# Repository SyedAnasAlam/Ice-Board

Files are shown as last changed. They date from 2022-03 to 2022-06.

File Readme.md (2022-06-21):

# Ice Board 
Ice Board is a FPGA development board containing the ICE40HX4k from Lattice.  
## Parts
- Lattice ICE40HX4K FPGA
- W25X20CL 2Mbit SPI Flash for storing configuration bitstream (104MHz)
- USB-C for configuring the FPGA using [IceBoard Programmer](https://github.com/SyedAnasAlam/IceBoard-Programmer) 
    - Also has option for programming the flash with a external device though breakout headers
- Requires 5V supply which can be supplied from either USB port or barrel jack (selectable with a header)
- FTDI4222 for USB to SPI conversion
- 64 x IO pins  
  
3D Rendering of the PCB

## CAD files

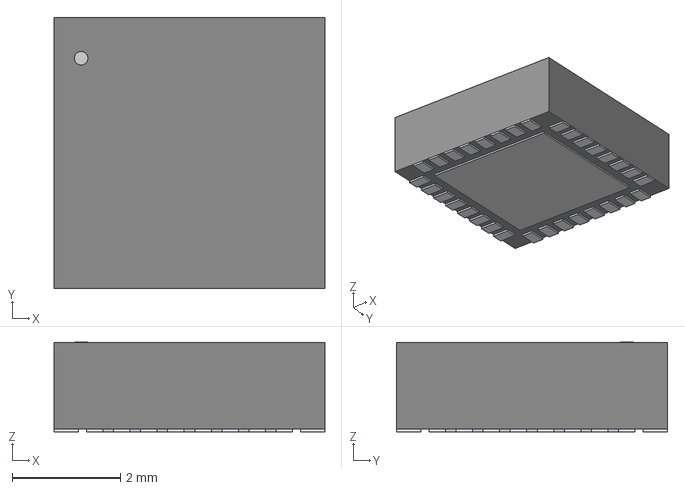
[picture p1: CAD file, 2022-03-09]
components/3D.models/FT4222HQ.step
5.00 x 5.00 x 1.65 mm

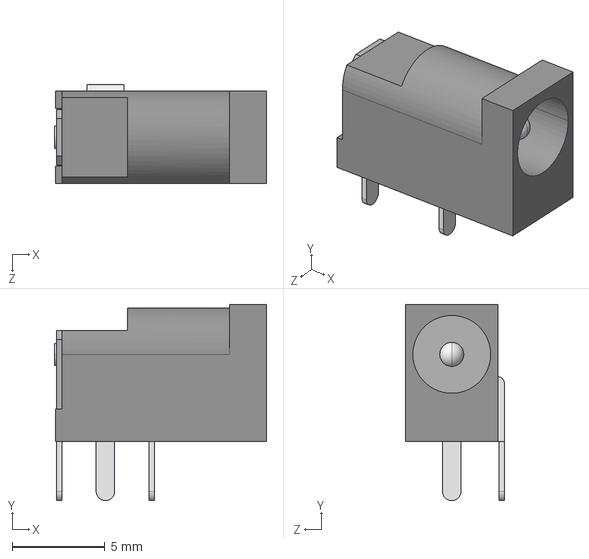
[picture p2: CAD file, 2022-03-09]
components/3D.models/CUI_DEVICES_PJ-007.step
11.5 x 10.6 x 5.35 mm

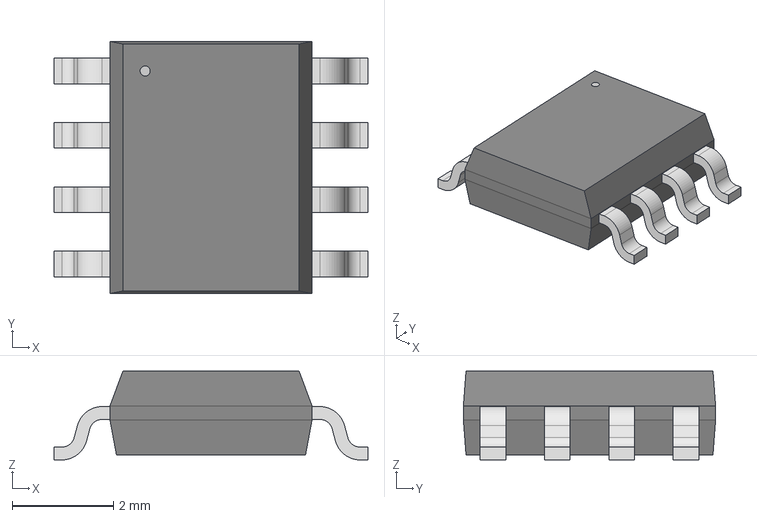
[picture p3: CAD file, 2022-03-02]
components/3D.models/W25X20CLSNIG.step
6.20 x 4.98 x 1.75 mm

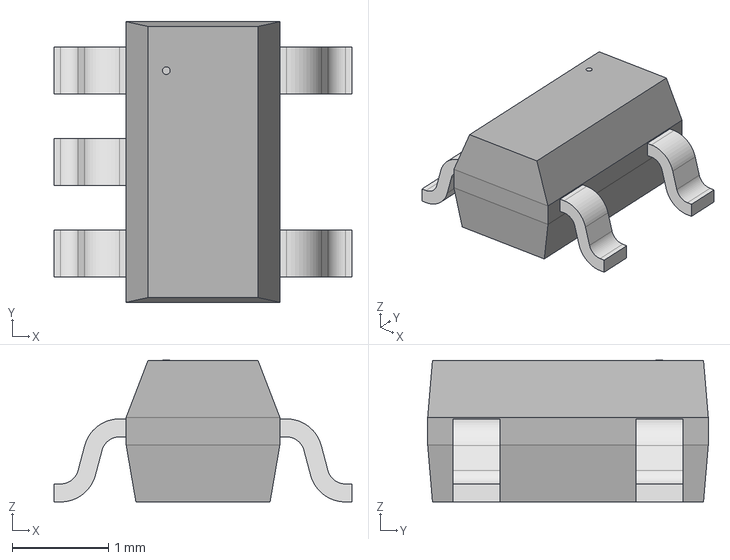
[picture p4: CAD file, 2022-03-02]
components/3D.models/SIT2001BC-S2-33E-25.0.step
3.10 x 2.92 x 1.48 mm

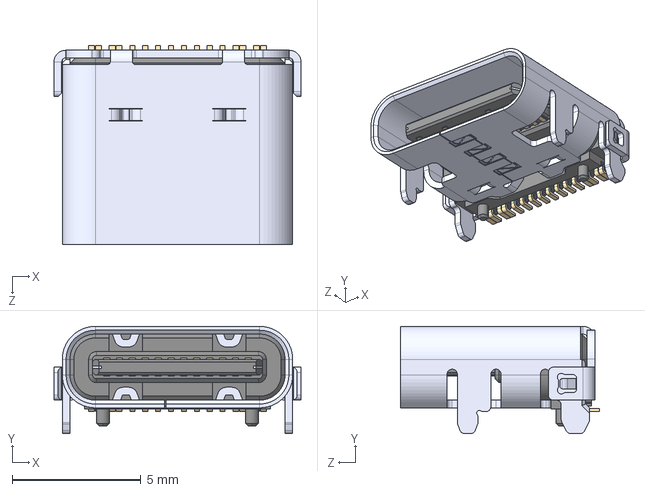
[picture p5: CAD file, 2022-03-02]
components/3D.models/USB_C.STEP
9.58 x 4.16 x 7.71 mm

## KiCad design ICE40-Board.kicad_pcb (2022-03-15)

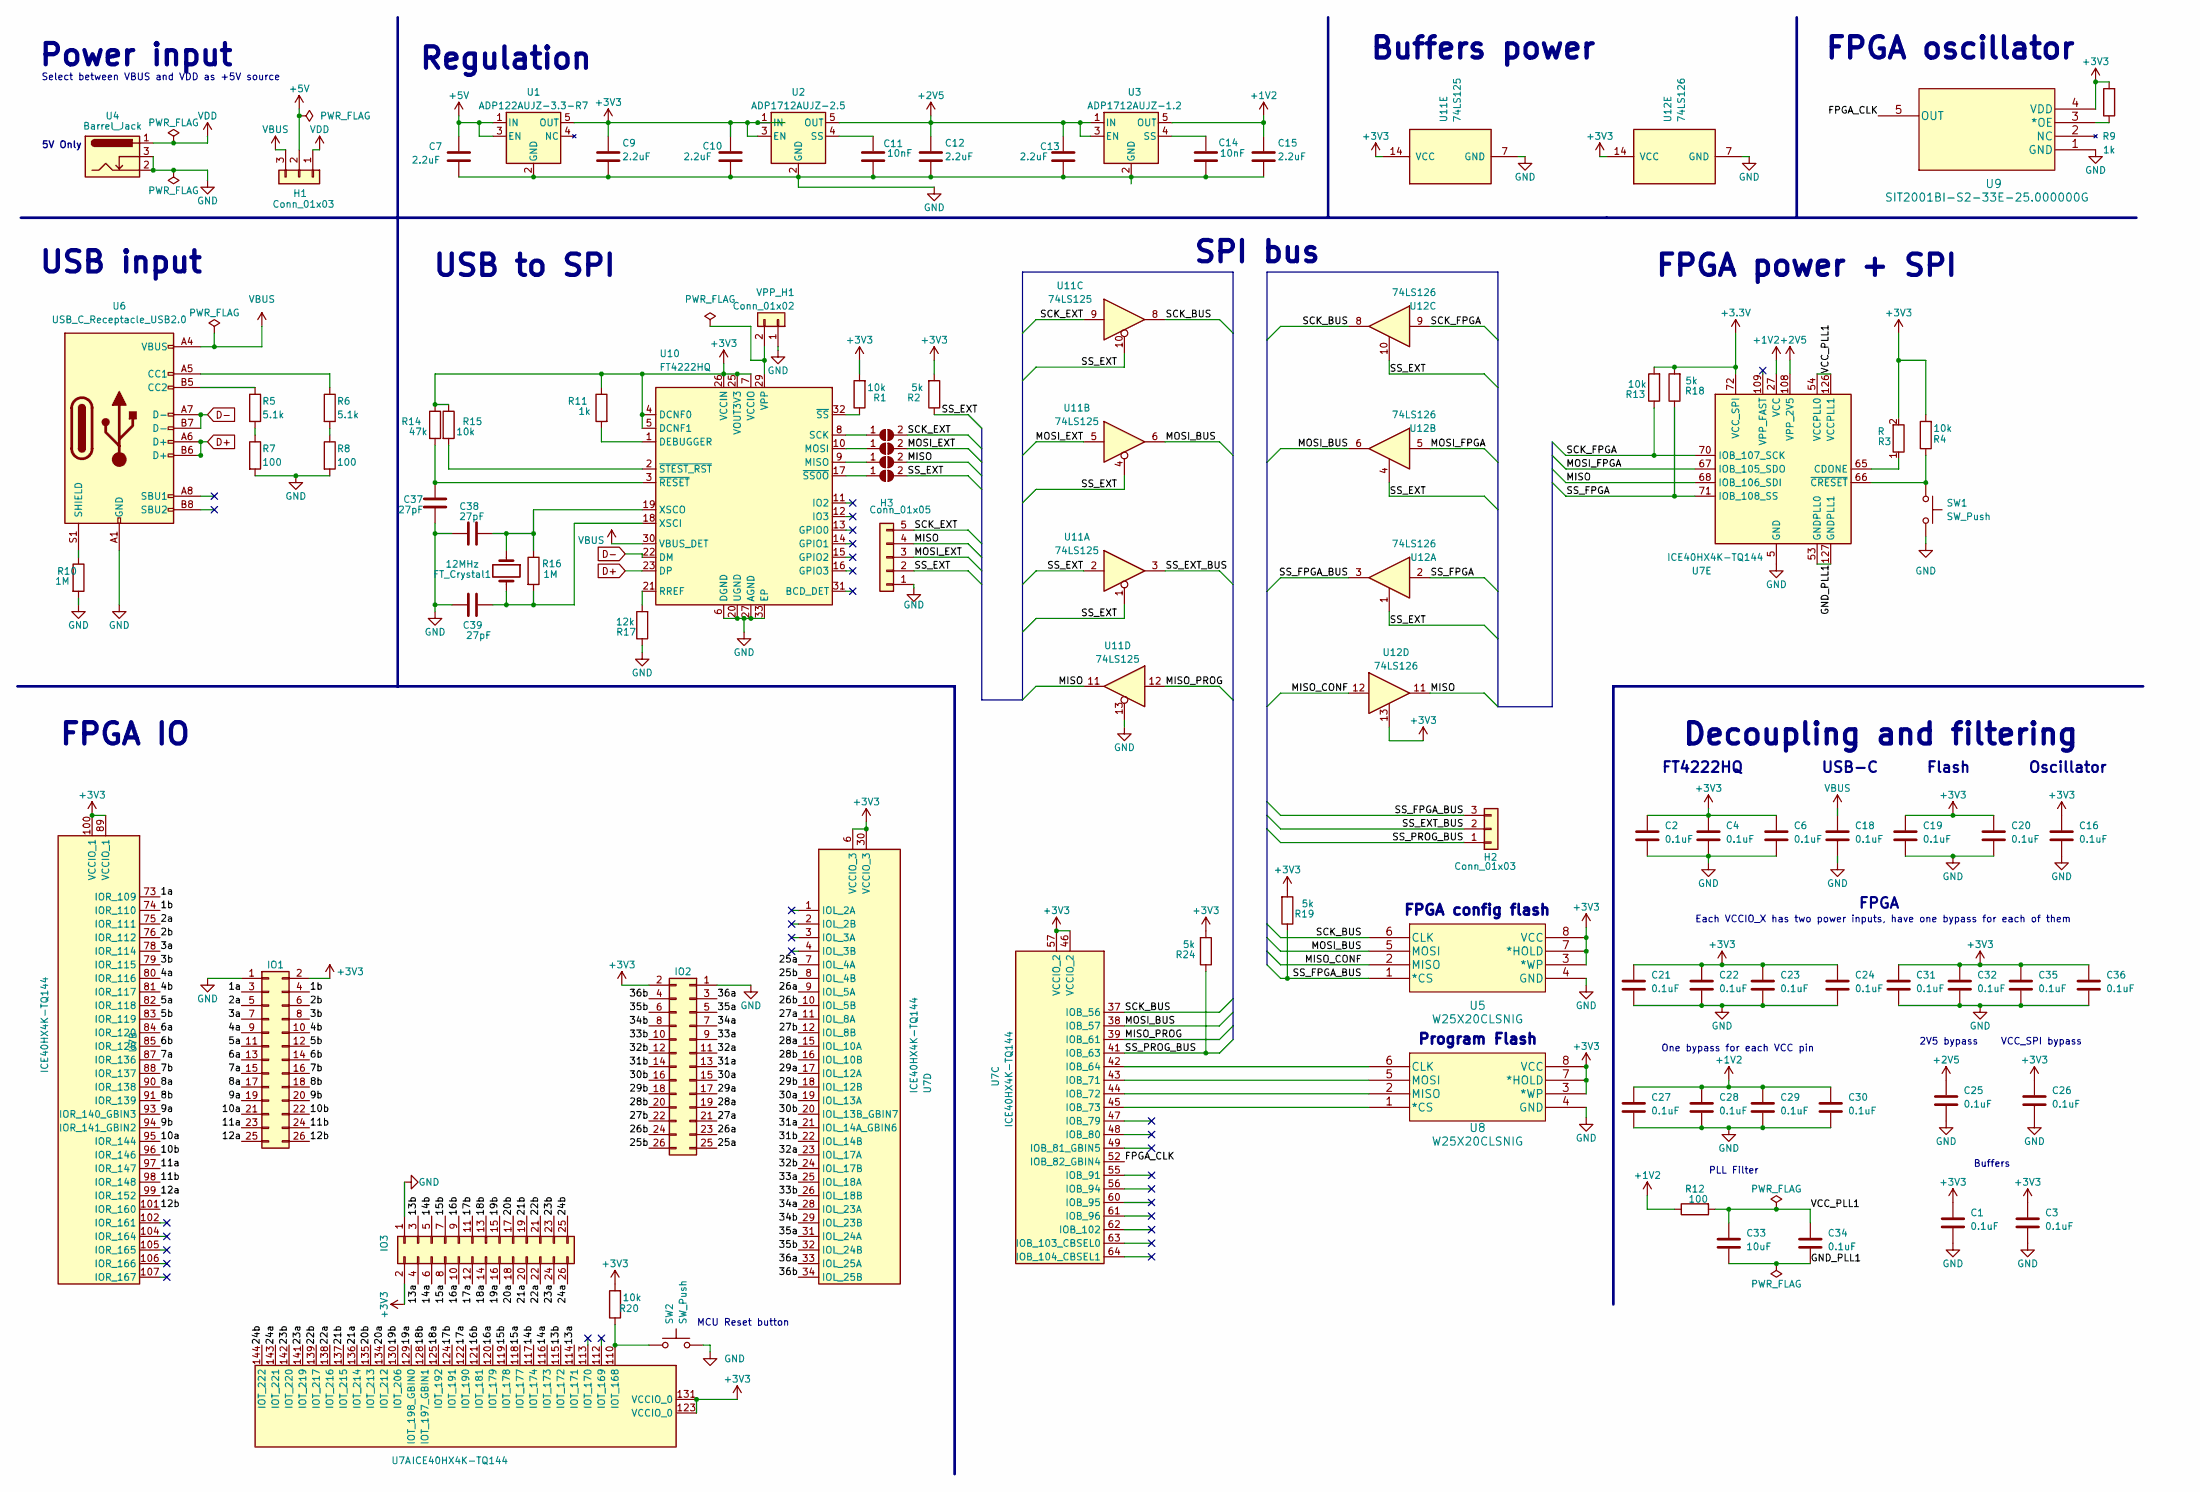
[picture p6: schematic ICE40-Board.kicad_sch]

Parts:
C1, C2, C3, C4, C6, C16, C18, C19, C20, C21, C22, C23, C24, C25, C26, C27, C28, C29, C30, C31, C32, C34, C35, C36: 0.1uF; C_0603_1608Metric_Pad1.08x0.95mm_HandSolder
C7, C9, C10, C12, C13, C15: 2.2uF; C_0603_1608Metric_Pad1.08x0.95mm_HandSolder
C11, C14: 10nF; C_0603_1608Metric_Pad1.08x0.95mm_HandSolder
C33: 10uF; C_0603_1608Metric_Pad1.08x0.95mm_HandSolder
C37, C38, C39: 27pF; C_0603_1608Metric_Pad1.08x0.95mm_HandSolder
FT_Crystal1: 12MHz; Crystal_HC49-U_Vertical
H1, H2: Conn_01x03; PinHeader_1x03_P2.54mm_Vertical
H3: Conn_01x05; PinHeader_1x05_P2.54mm_Vertical
IO1, IO2: Conn_02x13_Row_Letter_Last; PinHeader_2x13_P2.54mm_Vertical
IO3: Conn_02x09_Row_Letter_Last; PinHeader_2x13_P2.54mm_Vertical
JP2: SCK; SolderJumper-2_P1.3mm_Open_Pad1.0x1.5mm
JP3: MOSI; SolderJumper-2_P1.3mm_Open_Pad1.0x1.5mm
JP4: MISO; SolderJumper-2_P1.3mm_Open_Pad1.0x1.5mm
JP5: SS; SolderJumper-2_P1.3mm_Open_Pad1.0x1.5mm
R1, R4, R13, R15, R20: 10k; R_0603_1608Metric_Pad0.98x0.95mm_HandSolder
R2, R18, R19, R24: 5k; R_0603_1608Metric_Pad0.98x0.95mm_HandSolder
R3: R; R_0603_1608Metric_Pad0.98x0.95mm_HandSolder
R5, R6: 5.1k; R_0603_1608Metric_Pad0.98x0.95mm_HandSolder
R7, R8, R12: 100; R_0603_1608Metric_Pad0.98x0.95mm_HandSolder
R9, R11: 1k; R_0603_1608Metric_Pad0.98x0.95mm_HandSolder
R10, R16: 1M; R_0603_1608Metric_Pad0.98x0.95mm_HandSolder
R14: 47k; R_0603_1608Metric_Pad0.98x0.95mm_HandSolder
R17: 12k; R_0603_1608Metric_Pad0.98x0.95mm_HandSolder
SW1, SW2: SW_Push; SW_PUSH_6mm
U1: ADP122AUJZ-3.3-R7; SOT-23-5
U2: ADP1712AUJZ-2.5; SOT-23-5
U3: ADP1712AUJZ-1.2; SOT-23-5
U4: Barrel_Jack; CUI_PJ-007
U5, U8: W25X20CLSNIG; SOIC-8_3.9x4.9mm_P1.27mm
U6: USB_C_Receptacle_USB2.0; USB_C_Receptacle_Palconn_UTC16-G
U7: ICE40HX4K-TQ144; TQFP-144_20x20mm_P0.5mm
U9: SIT2001BI-S2-33E-25.000000G; SOT-23-5_HandSoldering
U10: FT4222HQ; VQFN-32-1EP_5x5mm_P0.5mm_EP3.1x3.1mm
U11: 74LS125; TSSOP-14_4.4x5mm_P0.65mm
U12: 74LS126; TSSOP-14_4.4x5mm_P0.65mm
VPP_H1: Conn_01x02; PinHeader_1x02_P2.54mm_Vertical

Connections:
+1V2: C15.1, C27.1, C28.1, C29.1, C30.1, R12.1, U3.5 (OUT), U7.27 (VCC), U7.40 (VCC), U7.92 (VCC), U7.111 (VCC)
+2V5: C12.1, C13.1, C25.1, U2.5 (OUT), U3.1 (IN), U3.3 (EN), U7.108 (VPP_2V5)
+5V: C7.1, H1.2, U1.1 (IN), U1.3 (EN)
/1a: IO1.3, U7.73 (IOR_109)
/1b: IO1.4, U7.74 (IOR_110)
/2a: IO1.5, U7.75 (IOR_111)
/2b: IO1.6, U7.76 (IOR_112)
/3a: IO1.7, U7.78 (IOR_114)
/3b: IO1.8, U7.79 (IOR_115)
/4a: IO1.9, U7.80 (IOR_116)
/4b: IO1.10, U7.81 (IOR_117)
/5a: IO1.11, U7.82 (IOR_118)
/5b: IO1.12, U7.83 (IOR_119)
/6a: IO1.13, U7.84 (IOR_120)
/6b: IO1.14, U7.85 (IOR_128)
/7a: IO1.15, U7.87 (IOR_136)
/7b: IO1.16, U7.88 (IOR_137)
/8a: IO1.17, U7.90 (IOR_138)
/8b: IO1.18, U7.91 (IOR_139)
/9a: IO1.19, U7.93 (IOR_140_GBIN3)
/9b: IO1.20, U7.94 (IOR_141_GBIN2)
/10a: IO1.21, U7.95 (IOR_144)
/10b: IO1.22, U7.96 (IOR_146)
/11a: IO1.23, U7.97 (IOR_147)
/11b: IO1.24, U7.98 (IOR_148)
/12a: IO1.25, U7.99 (IOR_152)
/12b: IO1.26, U7.101 (IOR_160)
/13a: IO3.4, U7.114 (IOT_171)
/13b: IO3.3, U7.115 (IOT_172)
/14a: IO3.6, U7.116 (IOT_173)
/14b: IO3.5, U7.117 (IOT_174)
/15a: IO3.8, U7.118 (IOT_177)
/15b: IO3.7, U7.119 (IOT_178)
/16a: IO3.10, U7.120 (IOT_179)
/16b: IO3.9, U7.121 (IOT_181)
/17a: IO3.12, U7.122 (IOT_190)
/17b: IO3.11, U7.124 (IOT_191)
/18a: IO3.14, U7.125 (IOT_192)
/18b: IO3.13, U7.128 (IOT_197_GBIN1)
/19a: IO3.16, U7.129 (IOT_198_GBIN0)
/19b: IO3.15, U7.130 (IOT_206)
/20a: IO3.18, U7.134 (IOT_212)
/20b: IO3.17, U7.135 (IOT_213)
/21a: IO3.20, U7.136 (IOT_214)
/21b: IO3.19, U7.137 (IOT_215)
/22a: IO3.22, U7.138 (IOT_216)
/22b: IO3.21, U7.139 (IOT_217)
/23a: IO3.24, U7.141 (IOT_219)
/23b: IO3.23, U7.142 (IOT_220)
/24a: IO3.26, U7.143 (IOT_221)
/24b: IO3.25, U7.144 (IOT_222)
/25a: IO2.25, U7.7 (IOL_4A)
/25b: IO2.26, U7.8 (IOL_4B)
/26a: IO2.23, U7.9 (IOL_5A)
/26b: IO2.24, U7.10 (IOL_5B)
/27a: IO2.21, U7.11 (IOL_8A)
/27b: IO2.22, U7.12 (IOL_8B)
/28a: IO2.19, U7.15 (IOL_10A)
/28b: IO2.20, U7.16 (IOL_10B)
/29a: IO2.17, U7.17 (IOL_12A)
/29b: IO2.18, U7.18 (IOL_12B)
/30a: IO2.15, U7.19 (IOL_13A)
/30b: IO2.16, U7.20 (IOL_13B_GBIN7)
/31a: IO2.13, U7.21 (IOL_14A_GBIN6)
/31b: IO2.14, U7.22 (IOL_14B)
/32a: IO2.11, U7.23 (IOL_17A)
/32b: IO2.12, U7.24 (IOL_17B)
/33a: IO2.9, U7.25 (IOL_18A)
/33b: IO2.10, U7.26 (IOL_18B)
/34a: IO2.7, U7.28 (IOL_23A)
/34b: IO2.8, U7.29 (IOL_23B)
/35a: IO2.5, U7.31 (IOL_24A)
/35b: IO2.6, U7.32 (IOL_24B)
/36a: IO2.3, U7.33 (IOL_25A)
/36b: IO2.4, U7.34 (IOL_25B)
/FPGA_CLK: U7.52 (IOB_82_GBIN4), U9.5 (OUT)
/GND_PLL1: C33.2, C34.2, U7.53 (GNDPLL0), U7.127 (GNDPLL1)
/MISO: H3.4, JP4.2 (B), U7.68 (IOB_106_SDI), U11.11, U12.11
/MISO_CONF: U5.2 (MISO), U12.12
/MISO_PROG: U7.39 (IOB_61), U11.12
/MOSI_BUS: U5.5 (MOSI), U7.38 (IOB_57), U11.6, U12.6
/MOSI_EXT: H3.3, JP3.2 (B), U11.5
/MOSI_FPGA: U7.67 (IOB_105_SDO), U12.5
/SCK_BUS: U5.6 (CLK), U7.37 (IOB_56), U11.8, U12.8
/SCK_EXT: H3.5, JP2.2 (B), U11.9
/SCK_FPGA: R13.1, U7.70 (IOB_107_SCK), U12.9
/SS_EXT: H3.2, JP5.2 (B), R2.1, U11.1, U11.2, U11.4, U11.10, U12.1, U12.4, U12.10
/SS_EXT_BUS: H2.2, U11.3
/SS_FPGA: R18.1, U7.71 (IOB_108_SS), U12.2
/SS_FPGA_BUS: H2.3, R19.1, U5.1 (*CS), U12.3
/SS_PROG_BUS: H2.1, R24.1, U7.41 (IOB_63)
/VCC_PLL1: C33.1, C34.1, R12.2, U7.54 (VCCPLL0), U7.126 (VCCPLL1)
D+: U6.A6 (D+), U6.B6 (D+), U10.23 (DP)
D-: U6.A7 (D-), U6.B7 (D-), U10.22 (DM)
GND: C1.2, C2.2, C3.2, C4.2, C6.2, C7.2, C9.2, C10.2, C11.2, C12.2, C13.2, C14.2, C15.2, C16.2, C18.2, C19.2, C20.2, C21.2, C22.2, C23.2, C24.2, C25.2, C26.2, C27.2, C28.2, C29.2, C30.2, C31.2, C32.2, C35.2, C36.2, C37.1, C38.2, C39.2, H3.1, IO1.1, IO2.1, IO3.1, R7.2, R8.2, R10.2, R17.1, SW1.2, SW2.2, U1.2 (GND), U2.2 (GND), U3.2 (GND), U4.2, U4.3, U5.4 (GND), U6.A1 (GND), U6.A12 (GND), U6.B1 (GND), U6.B12 (GND), U7.5 (GND), U7.13 (GND), U7.14 (GND), U7.59 (GND), U7.69 (GND), U7.86 (GND), U7.103 (GND), U7.132 (GND), U7.140 (GND), U8.4 (GND), U9.1 (GND), U10.6 (DGND), U10.20 (UGND), U10.24 (UGND), U10.27 (AGND), U10.28 (DGND), U10.33 (EP), U11.7 (GND), U11.13, U12.7 (GND), VPP_H1.1
unnamed: C11.1, U2.4 (SS)
unnamed: C14.1, U3.4 (SS)
unnamed: C37.2, R14.2, U10.3 (~RESET)
unnamed: C38.1, FT_Crystal1.1, R16.1, U10.19 (XSCO)
unnamed: C39.1, FT_Crystal1.2, R16.2, U10.18 (XSCI)
unnamed: JP2.1 (A), U10.8 (SCK)
unnamed: JP3.1 (A), U10.10 (MOSI)
unnamed: JP4.1 (A), U10.9 (MISO)
unnamed: JP5.1 (A), U10.17 (~SS0O)
unnamed: R1.1, U10.32 (~SS)
unnamed: R3.1, U7.65 (CDONE)
unnamed: R4.1, SW1.1, U7.66 (~CRESET)
unnamed: R5.1, U6.B5 (CC2)
unnamed: R5.2, R7.1
unnamed: R6.1, U6.A5 (CC1)
unnamed: R6.2, R8.1
unnamed: R9.1, U9.3 (*OE)
unnamed: R10.1, U6.S1 (SHIELD)
unnamed: R11.2, U10.1 (DEBUGGER)
unnamed: R15.2, U10.2 (~STEST_RST)
unnamed: R17.2, U10.21 (RREF)
unnamed: R20.1, SW2.1, U7.110 (IOT_168)
unnamed: U7.42 (IOB_64), U8.6 (CLK)
unnamed: U7.43 (IOB_71), U8.5 (MOSI)
unnamed: U7.44 (IOB_72), U8.2 (MISO)
unnamed: U7.45 (IOB_73), U8.1 (*CS)
unnamed: U10.29 (VPP), VPP_H1.2
VBUS: C18.1, H1.3, U6.A4 (VBUS), U6.A9 (VBUS), U6.B4 (VBUS), U6.B9 (VBUS), U10.30 (VBUS_DET)
VDD: H1.1, U4.1

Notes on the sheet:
Regulation
MCU Reset button
USB-C
Program Flash
USB to SPI
FT4222HQ
Select between VBUS and VDD as +5V source
SPI bus
USB input
Flash
Buffers power
Buffers
FPGA oscillator
5V Only
Oscillator
FPGA power + SPI
One bypass for each VCC pin
FPGA config flash
PLL Filter
VCC_SPI bypass
Decoupling and filtering
Power input
FPGA IO
2V5 bypass
FPGA
Each VCCIO_X has two power inputs, have one bypass for each of them

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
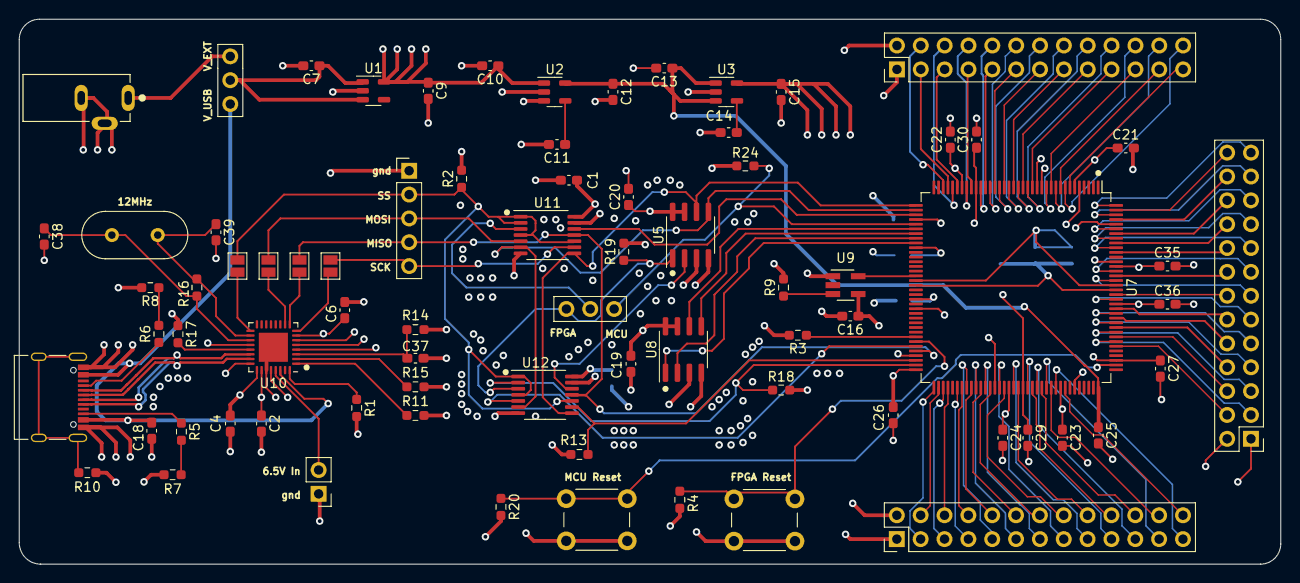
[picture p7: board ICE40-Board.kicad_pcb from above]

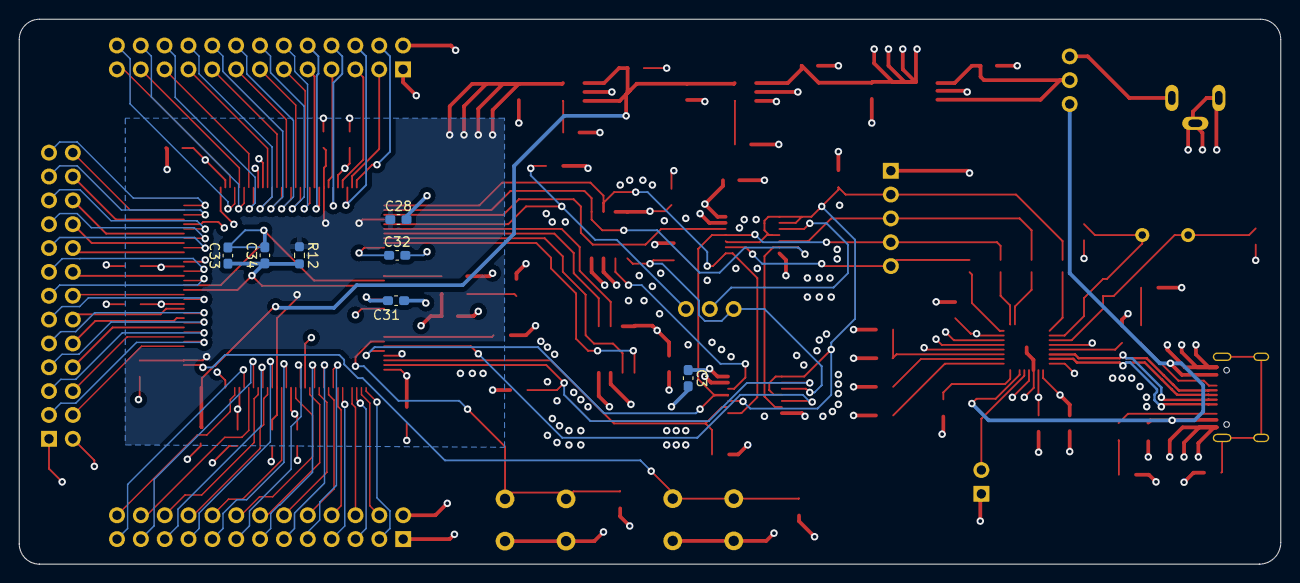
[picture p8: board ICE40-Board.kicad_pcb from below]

Board: 4 copper layers, 134.4 x 58.0 mm, 83 parts (7 on the bottom side), 125 nets.

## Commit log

2022-03-02 First revision of schematic layout, no errors in ERC
    [ICE40-Board.kicad_pcb, ICE40-Board.kicad_sch, SIT2001BC-S2-33E-25.0.step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]
2022-03-02 Starting routing
    [ICE40-Board.kicad_pcb, ICE40-Board.kicad_sch]
2022-03-02 Changed reference designation method to simple letter + number
    [ICE40-Board.kicad_sch]
2022-03-02 Begun initial routing with simple reference designation
    [ICE40-Board.kicad_pcb, ICE40-Board.kicad_sch]
2022-03-03 Committing before changing footprints to hand solder version for resistors and capacitors
    [ICE40-Board.kicad_pcb, ICE40-Board.kicad_sch]
2022-03-05 Initial routing
    [ICE40-Board.kicad_pcb, ICE40-Board.kicad_sch]
2022-03-06 USB-C routing complete
    [ICE40-Board.kicad_pcb, ICE40-Board.kicad_sch]
2022-03-08 Routing buffers and flash
    [ICE40-Board.kicad_pcb, ICE40-Board.kicad_sch]
2022-03-09 Allowing MISO for both config and program flash when programming
    [ICE40-Board.kicad_sch]
2022-03-09 everything routed just IO pins remaining
    [ICE40-Board.kicad_pcb, ICE40-Board.kicad_sch]
2022-03-09 previous commit message incorrect, this commit has fully routed design except IO
    [ICE40-Board.kicad_pcb]
2022-03-09 No DRC errors, board fully routed
    [CUI_DEVICES_PJ-007.step, FT4222HQ.step, ICE40-Board.kicad_pcb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]
2022-03-09 Minor changed
    [ICE40-Board.kicad_pcb]
2022-03-10 Adjusted component and track clearances
    [ICE40-Board.kicad_pcb, ICE40-Board.kicad_sch]
2022-03-10 Impedance controlled USB routing
    [ICE40-Board.kicad_pcb]
2022-03-10 Added ground vias for better signal integrity, added silkscreen text, added reset button for MCU
    [ICE40-Board.kicad_pcb, ICE40-Board.kicad_sch]
2022-03-10 Added dimension
    [ICE40-Board.kicad_pcb]
2022-03-10 Placed vias around SPI lines, placed main oscillator closer to FPGA
    [ICE40-Board.kicad_pcb, ICE40-Board.kicad_sch]
2022-03-15 Version 1.0 completed
    [ICE40-Board.kicad_pcb]
